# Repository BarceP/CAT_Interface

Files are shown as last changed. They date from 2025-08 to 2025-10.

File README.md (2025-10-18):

# CAT_Interface
Radio control and audio bridge.

- Isolated digital/audio Bridge
- Usb C (2.0) connector
- Analog Gain Control
- single DB9 output connector for easy cabling.

Version 2.0:

- Due to issues it was migrated to a uC for better compatibility (in revision an STM32F072)
- Still in development

Open Hardware (CERN OHW Licence)

## TODO

- [X] Connettore Prog.
- [X] Bypass Trafo
- [X] Opt aggiungere extra opto
- [X] Silkscreen (add Group)
- [X] Zenerino + R serie su TX
- [X] Togliere RS232
- [X] Verificare BOOT0

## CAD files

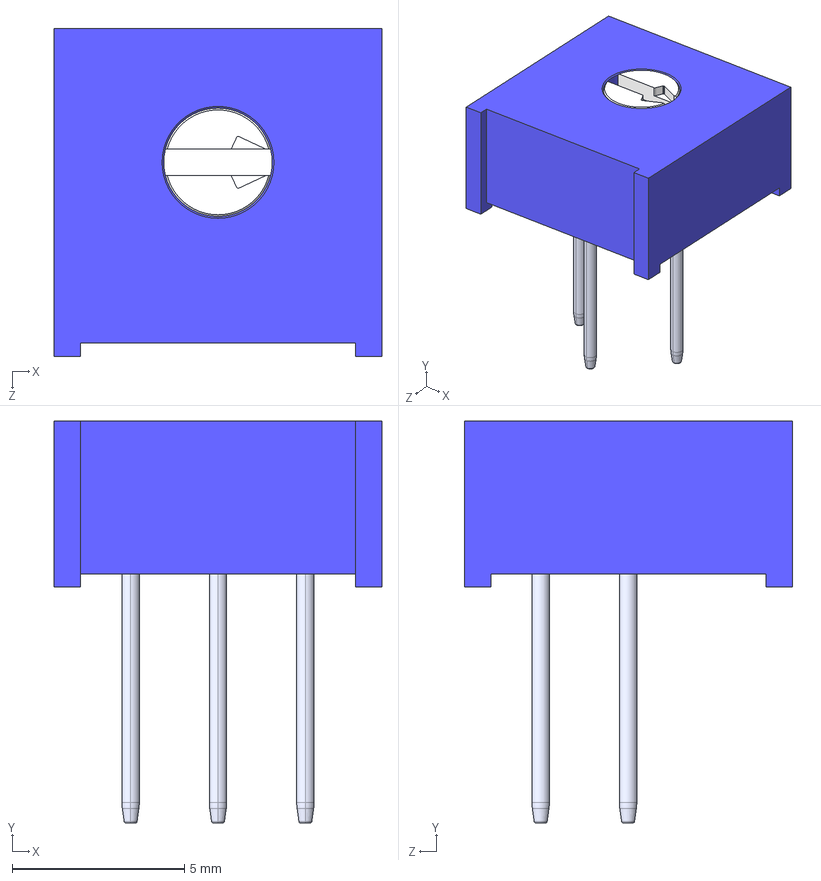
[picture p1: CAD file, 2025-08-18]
3386P-1-103.STEP
9.53 x 11.7 x 9.53 mm

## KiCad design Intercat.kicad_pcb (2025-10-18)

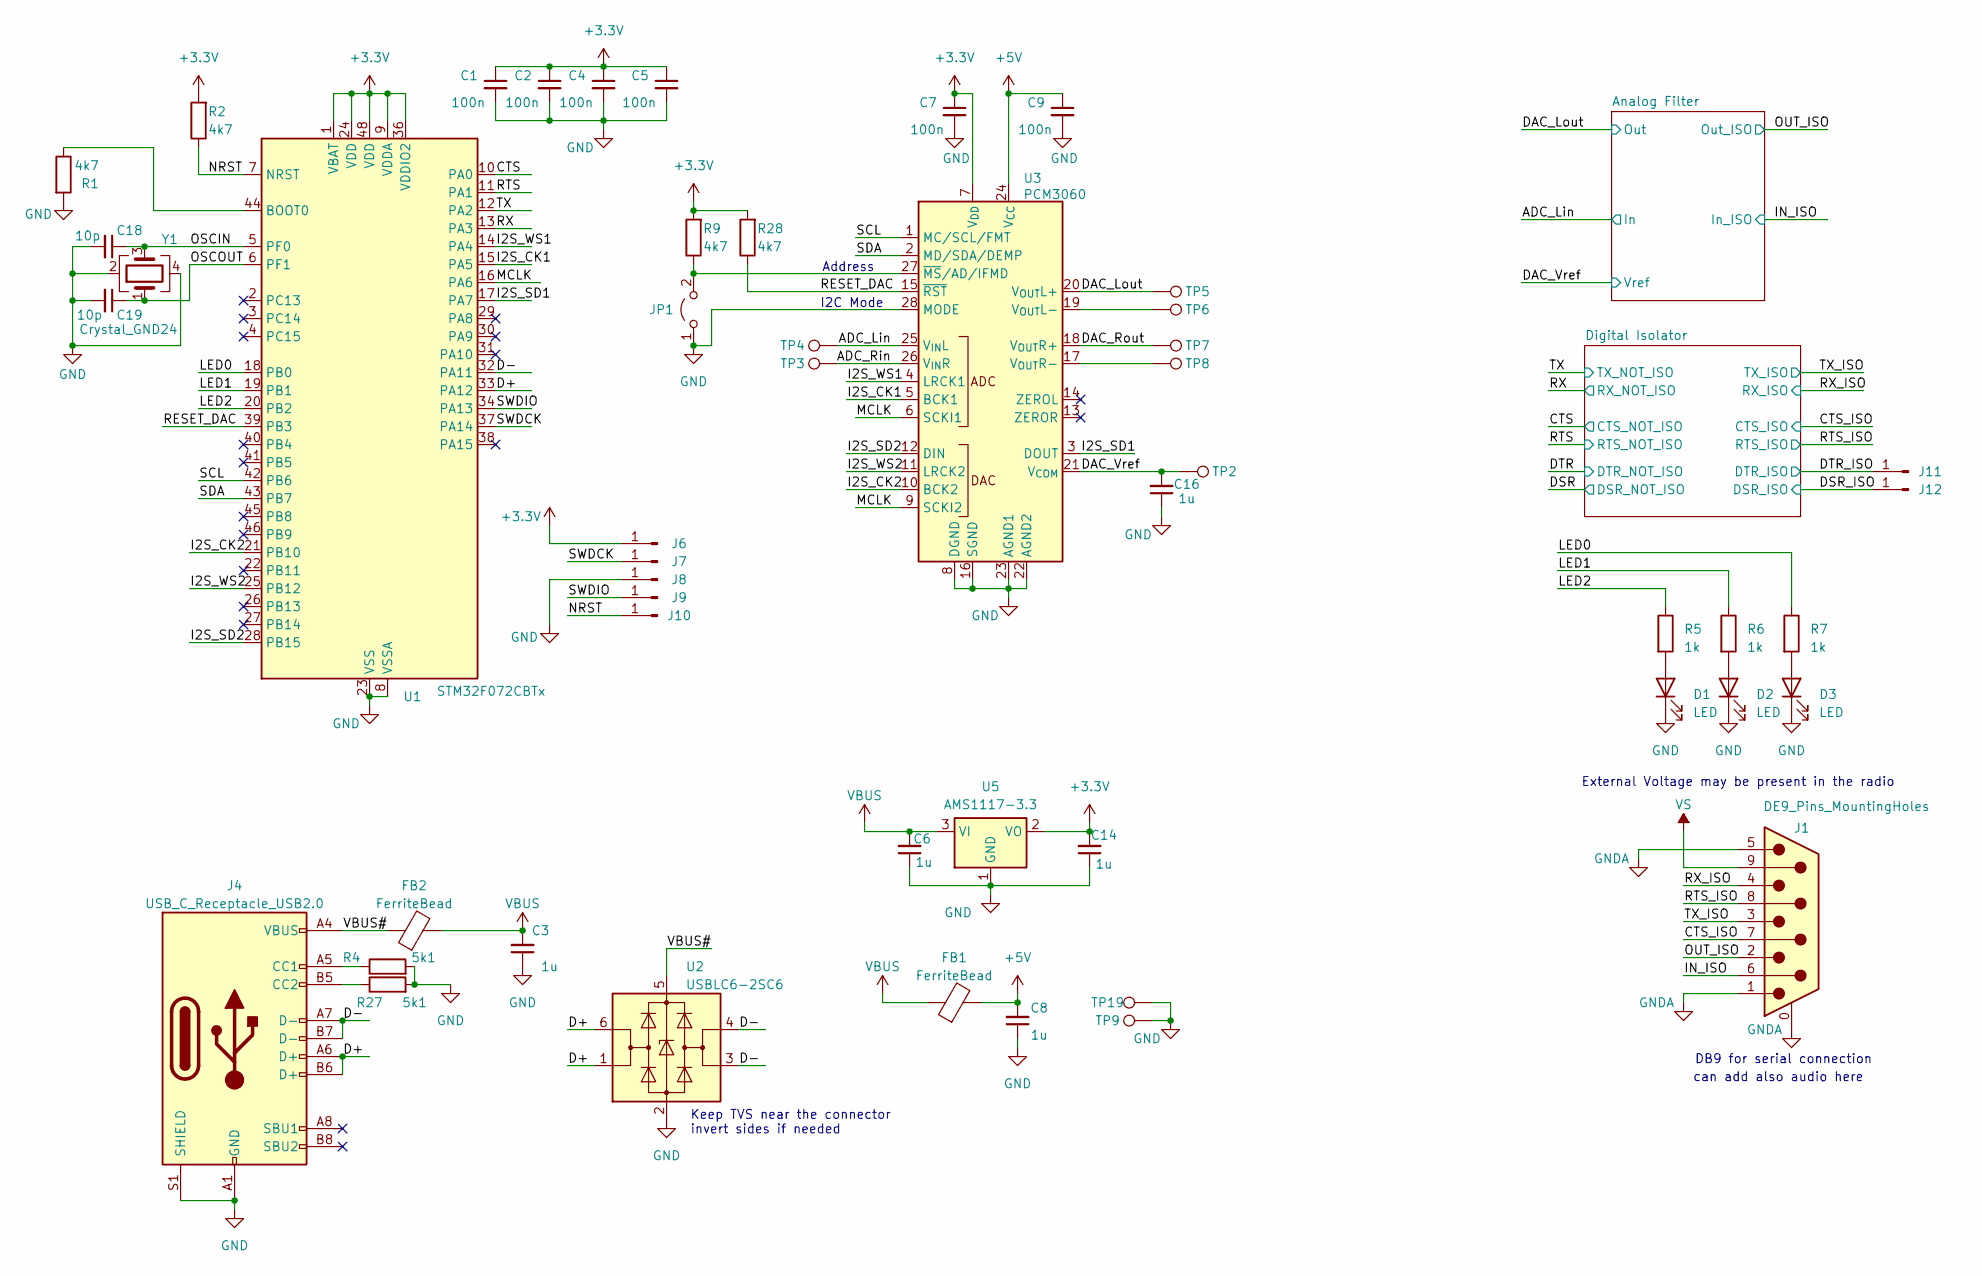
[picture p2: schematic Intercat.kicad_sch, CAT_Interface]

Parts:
C1, C2, C4, C5, C7, C9: 100n; C_0603_1608Metric; LCSC C14663
C3, C6, C8, C14, C16: 1u; C_0805_2012Metric; LCSC C28323
C18, C19: 10p; C_0603_1608Metric
D1, D2, D3: LED; LED_0603_1608Metric; LCSC C2286
FB1, FB2: FerriteBead; R_0603_1608Metric; LCSC C1002
J1: DE9_Pins_MountingHoles; DSUB-9_Pins_Horizontal_P2.77x2.84mm_EdgePinOffset4.94mm_Hou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
J4: USB_C_Receptacle_USB2.0; USB_C_Receptacle_GCT_USB4105-xx-A_16P_TopMnt_Horizontal; LCSC C2927038
J6, J11: Conn_01x01_Pin; SolderWirePad_1x01_SMD_1x2mm
J7, J12: SWDCLK; SolderWirePad_1x01_SMD_1x2mm
J8: GND; SolderWirePad_1x01_SMD_1x2mm
J9: SWDIO; SolderWirePad_1x01_SMD_1x2mm
J10: NRST; SolderWirePad_1x01_SMD_1x2mm
JP1: Jumper_2_Open; SolderJumper-2_P1.3mm_Open_RoundedPad1.0x1.5mm
R1, R2, R9, R28: 4k7; R_0603_1608Metric; LCSC C23162
R4, R27: 5k1; R_0603_1608Metric; LCSC C23186
R5, R6, R7: 1k; R_0603_1608Metric; LCSC C21190
TP2, TP3, TP4, TP5, TP6, TP7, TP8, TP9, TP19: TestPoint; TestPoint_Pad_D1.5mm
U1: STM32F072CBTx; LQFP-48_7x7mm_P0.5mm
U2: USBLC6-2SC6; SOT-23-6; LCSC C5261088
U3: PCM3060; TSSOP-28_4.4x9.7mm_P0.65mm
U5: AMS1117-3.3; SOT-223-3_TabPin2
Y1: Crystal_GND24; Crystal_SMD_3225-4Pin_3.2x2.5mm

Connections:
+3.3V: C1.1, C2.1, C4.1, C5.1, C7.1, C14.2, J6.1, R2.2, R9.2, R28.2, U1.1 (VBAT), U1.9 (VDDA), U1.24 (VDD), U1.36 (VDDIO2), U1.48 (VDD), U3.7 (V_{DD}), U5.2 (VO); also elsewhere on the board
+5V: C8.2, C9.1, FB1.2, U3.24 (V_{CC}); also elsewhere on the board
/ADC_Lin: TP4.1, U3.25 (V_{IN}L); also elsewhere on the board
/ADC_Rin: TP3.1, U3.26 (V_{IN}R)
/CTS: U1.10 (PA0); also elsewhere on the board
/CTS_ISO: J1.7; also elsewhere on the board
/D+: J4.A6 (D+), J4.B6 (D+), U1.33 (PA12), U2.1 (I/O1), U2.6 (I/O1)
/D-: J4.A7 (D-), J4.B7 (D-), U1.32 (PA11), U2.3 (I/O2), U2.4 (I/O2)
/DAC_Lout: TP5.1, U3.20 (V_{OUT}L+); also elsewhere on the board
/DAC_Rout: TP7.1, U3.18 (V_{OUT}R+)
/DAC_Vref: C16.2, TP2.1, U3.21 (V_{COM}); also elsewhere on the board
/DSR_ISO: J12.1; also elsewhere on the board
/DTR_ISO: J11.1; also elsewhere on the board
/I2S_CK1: U1.15 (PA5), U3.5 (BCK1)
/I2S_CK2: U1.21 (PB10), U3.10 (BCK2)
/I2S_SD1: U1.17 (PA7), U3.3 (DOUT)
/I2S_SD2: U1.28 (PB15), U3.12 (DIN)
/I2S_WS1: U1.14 (PA4), U3.4 (LRCK1)
/I2S_WS2: U1.25 (PB12), U3.11 (LRCK2)
/IN_ISO: J1.6; also elsewhere on the board
/LED0: R7.1, U1.18 (PB0)
/LED1: R6.1, U1.19 (PB1)
/LED2: R5.1, U1.20 (PB2)
/MCLK: U1.16 (PA6), U3.6 (SCKI1), U3.9 (SCKI2)
/NRST: J10.1, R2.1, U1.7 (NRST)
/OSCIN: C18.1, U1.5 (PF0), Y1.3
/OSCOUT: C19.1, U1.6 (PF1), Y1.1
/OUT_ISO: J1.2; also elsewhere on the board
/RESET_DAC: R28.1, U1.39 (PB3), U3.15 (~RST)
/RTS: U1.11 (PA1); also elsewhere on the board
/RTS_ISO: J1.8; also elsewhere on the board
/RX: U1.13 (PA3); also elsewhere on the board
/RX_ISO: J1.4; also elsewhere on the board
/SCL: U1.42 (PB6), U3.1 (MC/SCL/FMT)
/SDA: U1.43 (PB7), U3.2 (MD/SDA/DEMP)
/SWDCK: J7.1, U1.37 (PA14)
/SWDIO: J9.1, U1.34 (PA13)
/TX: U1.12 (PA2); also elsewhere on the board
/TX_ISO: J1.3; also elsewhere on the board
/VBUS#: FB2.1, J4.A4 (VBUS), J4.A9 (VBUS), J4.B4 (VBUS), J4.B9 (VBUS), U2.5 (VBUS)
GND: C1.2, C2.2, C3.1, C4.2, C5.2, C6.1, C7.2, C8.1, C9.2, C14.1, C16.1, C18.2, C19.2, D1.1 (K), D2.1 (K), D3.1 (K), J4.A1 (GND), J4.A12 (GND), J4.B1 (GND), J4.B12 (GND), J4.S1 (SHIELD), J8.1, JP1.1 (A), R1.2, R4.2, R27.2, TP9.1, TP19.1, U1.8 (VSSA), U1.23 (VSS), U1.35 (VSS), U1.47 (VSS), U2.2 (GND), U3.8 (DGND), U3.16 (SGND), U3.22 (AGND2), U3.23 (AGND1), U3.28 (MODE), U5.1 (GND), Y1.2, Y1.4; also elsewhere on the board
GNDA: J1.0 (PAD), J1.1, J1.5; also elsewhere on the board
unnamed: D1.2 (A), R5.2
unnamed: D2.2 (A), R6.2
unnamed: D3.2 (A), R7.2
unnamed: J4.A5 (CC1), R4.1
unnamed: J4.B5 (CC2), R27.1
unnamed: JP1.2 (B), R9.1, U3.27 (~MS/AD/IFMD)
unnamed: R1.1, U1.44 (BOOT0)
unnamed: TP6.1, U3.19 (V_{OUT}L-)
unnamed: TP8.1, U3.17 (V_{OUT}R-)
VBUS: C3.2, C6.2, FB1.1, FB2.2, U5.3 (VI)
VS: J1.9; also elsewhere on the board

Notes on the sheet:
can add also audio here
Address
External Voltage may be present in the radio
I2C Mode
DB9 for serial connection
Keep TVS near the connector invert sides if needed

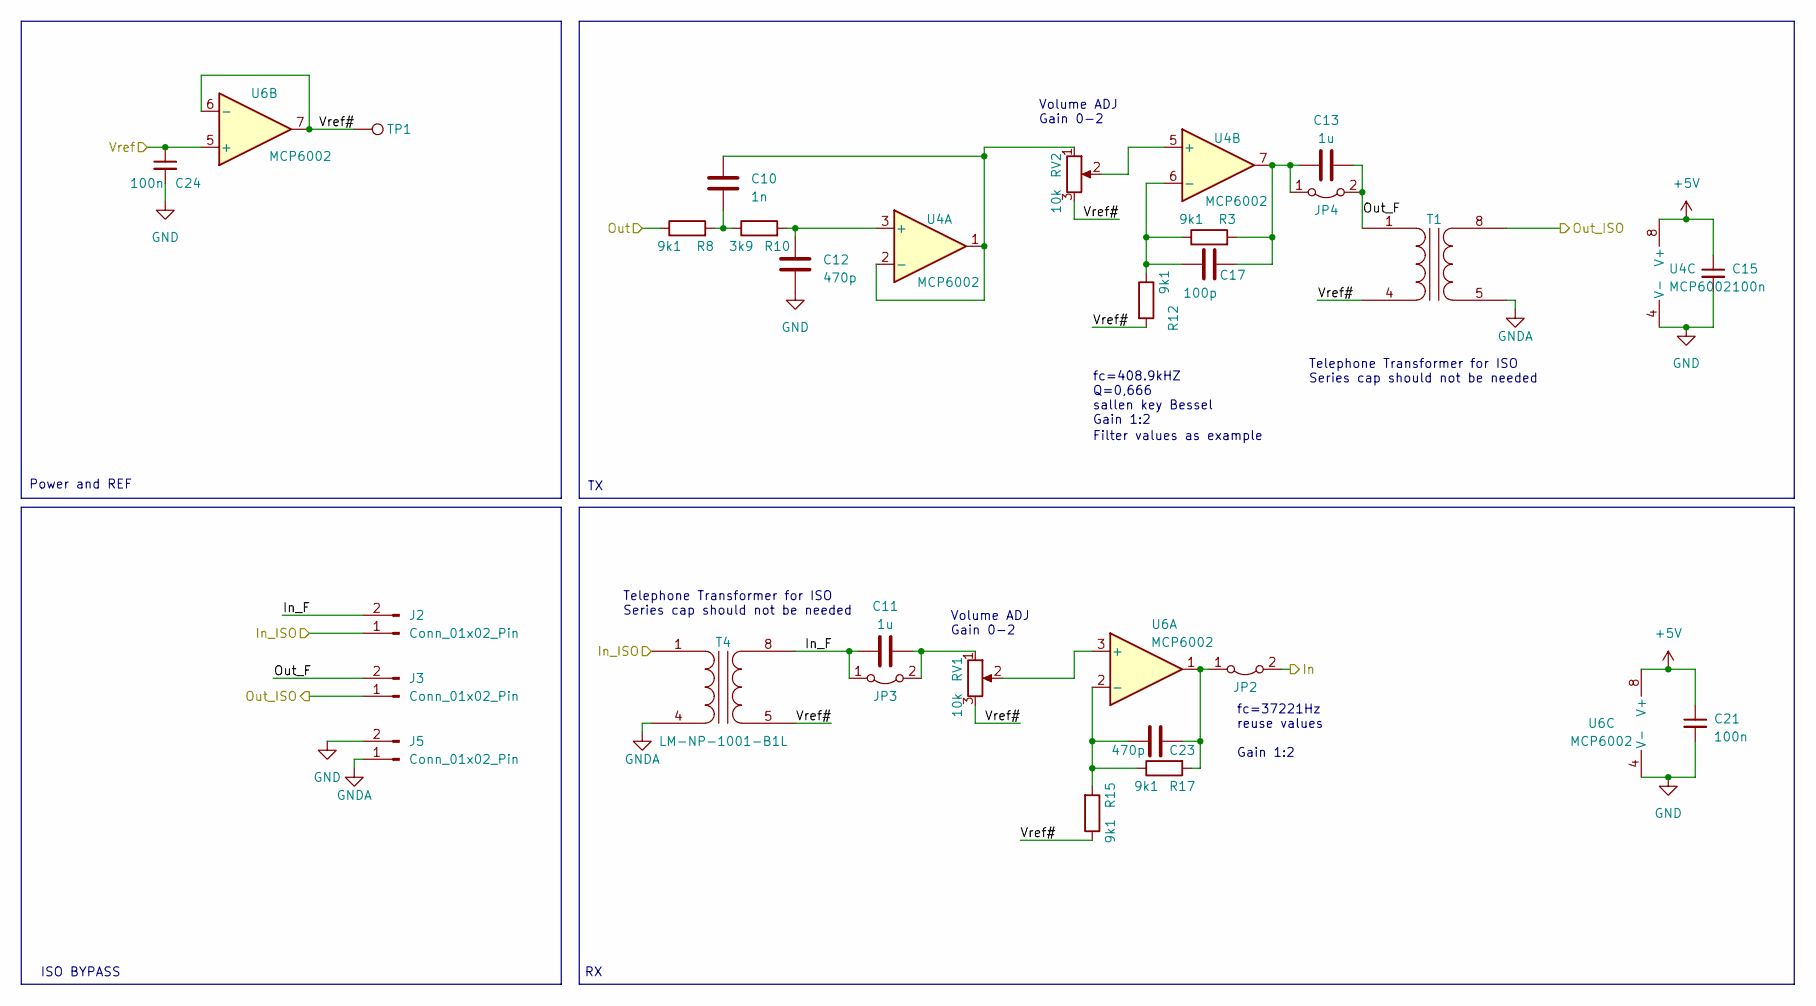
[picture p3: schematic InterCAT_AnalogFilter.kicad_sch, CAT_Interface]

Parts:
C10: 1n; C_0603_1608Metric
C11, C13: 1u; C_0805_2012Metric; LCSC C28323
C12, C23: 470p; C_0603_1608Metric; LCSC C1620
C15, C21, C24: 100n; C_0603_1608Metric; LCSC C14663
C17: 100p; C_0603_1608Metric
J2, J3, J5: Conn_01x02_Pin; PinHeader_1x02_P2.54mm_Vertical
JP2, JP3, JP4: Jumper_2_Bridged; SolderJumper-2_P1.3mm_Bridged_RoundedPad1.0x1.5mm
R3, R8, R12, R15, R17: 9k1; R_0603_1608Metric; LCSC C23260
R10: 3k9; R_0603_1608Metric; LCSC C23018
RV1, RV2: 10k; Potentiometer_Bourns_3386P_Vertical
T1, T4: LM-NP-1001-B1L; LCSC C5361839
TP1: TestPoint; TestPoint_Pad_D1.5mm
U4, U6: MCP6002; SOIC-8_3.9x4.9mm_P1.27mm; LCSC C7377

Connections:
+5V: C15.1, C21.1, U4.8 (V+), U6.8 (V+); also elsewhere on the board
/ADC_Lin: JP2.2 (B); also elsewhere on the board
/Analog Filter/In_F: C11.1, J2.2, JP3.1 (A), T4.8 (SB)
/Analog Filter/Out_F: C13.2, J3.2, JP4.2 (B), T1.1 (AA)
/Analog Filter/Vref#: R12.2, R15.1, RV1.3, RV2.3, T1.4 (AB), T4.5 (SA), TP1.1, U6.6 (-), U6.7
/DAC_Lout: R8.1; also elsewhere on the board
/DAC_Vref: C24.1, U6.5 (+); also elsewhere on the board
/IN_ISO: J2.1, T4.1 (AA); also elsewhere on the board
/OUT_ISO: J3.1, T1.8 (SB); also elsewhere on the board
GND: C12.2, C15.2, C21.2, C24.2, J5.2, U4.4 (V-), U6.4 (V-); also elsewhere on the board
GNDA: J5.1, T1.5 (SA), T4.4 (AB); also elsewhere on the board
unnamed: C10.2, R8.2, R10.1
unnamed: C23.2, JP2.1 (A), R17.2, U6.1
unnamed: C11.2, JP3.2 (B), RV1.1
unnamed: C13.1, C17.2, JP4.1 (A), R3.2, U4.7
unnamed: C12.1, R10.2, U4.3 (+)
unnamed: C10.1, RV2.1, U4.1, U4.2 (-)
unnamed: RV2.2, U4.5 (+)
unnamed: C17.1, R3.1, R12.1, U4.6 (-)
unnamed: RV1.2, U6.3 (+)
unnamed: C23.1, R15.2, R17.1, U6.2 (-)

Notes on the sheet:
Power and REF
fc=37221Hz reuse values Gain 1:2
Telephone Transformer for ISO Series cap should not be needed
Filter values as example
Volume ADJ Gain 0-2
fc=408.9kHZ Q=0,666 sallen key Bessel Gain 1:2
ISO BYPASS

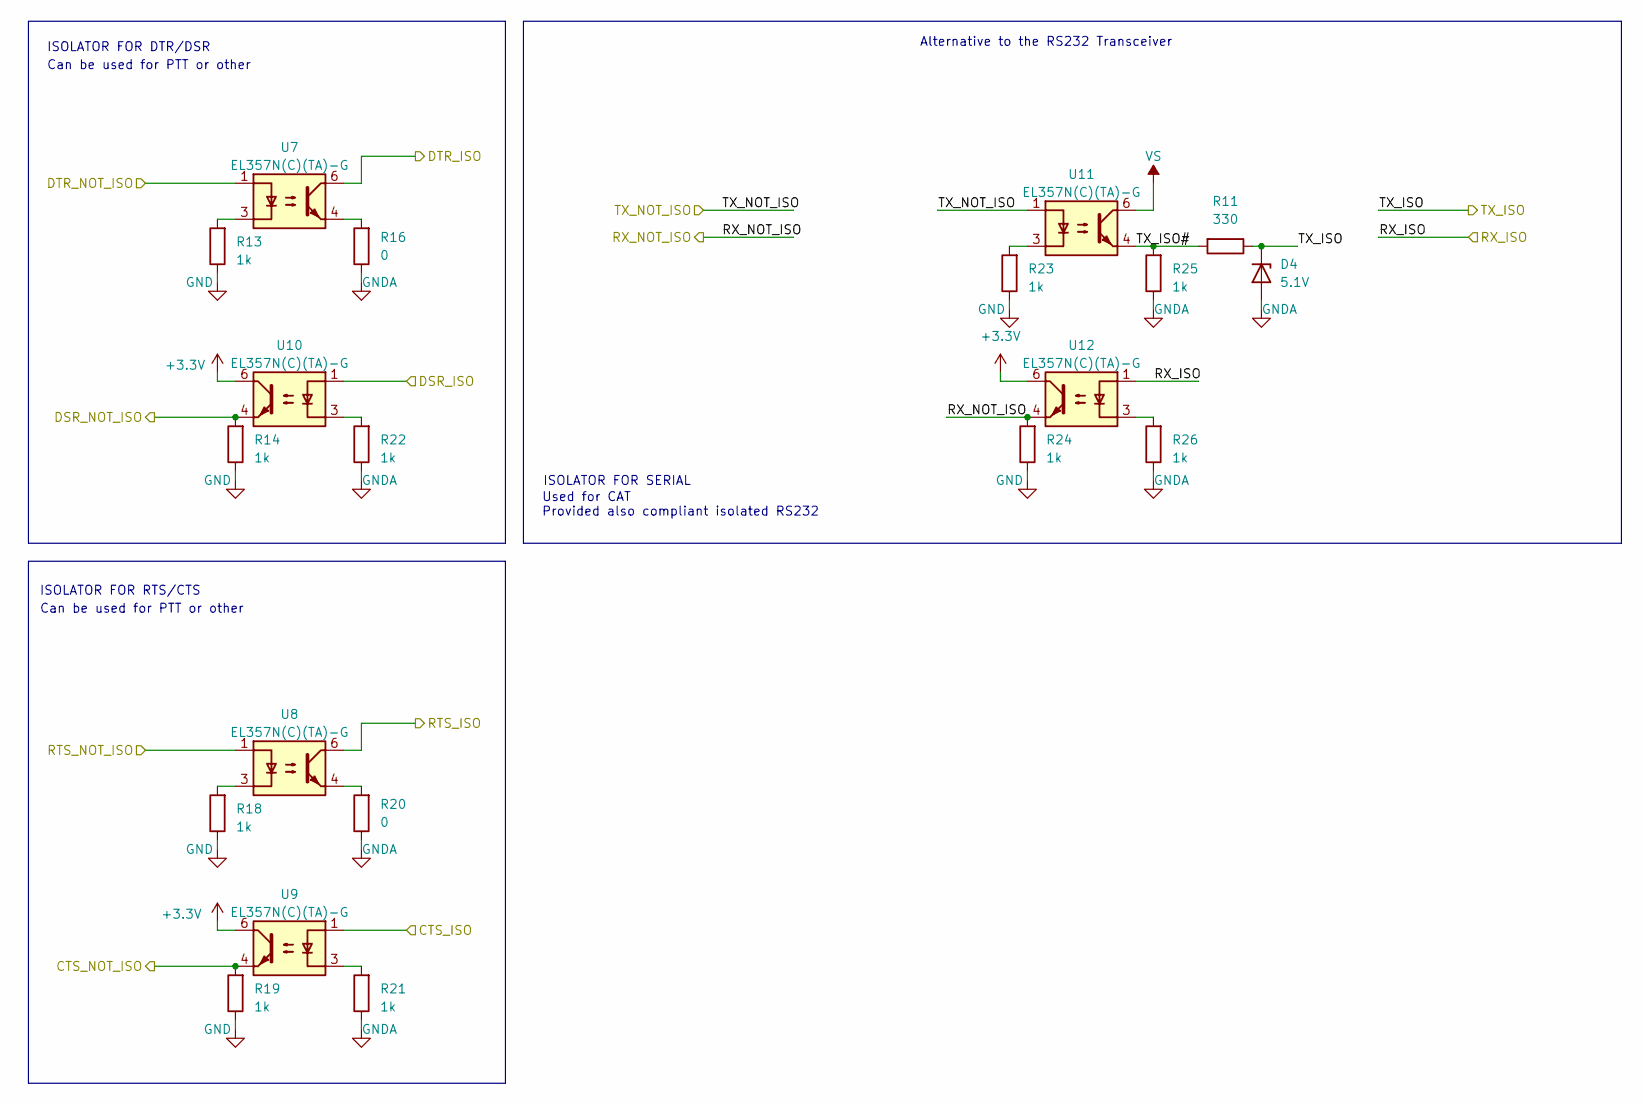
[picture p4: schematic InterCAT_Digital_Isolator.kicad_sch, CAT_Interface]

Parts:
D4: 5.1V; D_0603_1608Metric
R11: 330; R_0603_1608Metric
R13, R14, R18, R19, R21, R22, R23, R24, R25, R26: 1k; R_0603_1608Metric; LCSC C21190
R16, R20: 0; R_0603_1608Metric
U7, U8, U9, U10, U11, U12: EL357N(C)(TA)-G; SO-6-4_4.4x3.9mm_P2.54mm; LCSC C29981

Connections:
+3.3V: U9.6, U10.6, U12.6; also elsewhere on the board
/CTS: R19.2, U9.4; also elsewhere on the board
/CTS_ISO: U9.1; also elsewhere on the board
/DSR: R14.2, U10.4
/DSR_ISO: U10.1; also elsewhere on the board
/DTR: U7.1
/DTR_ISO: U7.6; also elsewhere on the board
/Digital Isolator/TX_ISO#: R11.2, R25.2, U11.4
/RTS: U8.1; also elsewhere on the board
/RTS_ISO: U8.6; also elsewhere on the board
/RX: R24.2, U12.4; also elsewhere on the board
/RX_ISO: U12.1; also elsewhere on the board
/TX: U11.1; also elsewhere on the board
/TX_ISO: D4.1 (K), R11.1; also elsewhere on the board
GND: R13.1, R14.1, R18.1, R19.1, R23.1, R24.1; also elsewhere on the board
GNDA: D4.2 (A), R16.1, R20.1, R21.1, R22.1, R25.1, R26.1; also elsewhere on the board
unnamed: R13.2, U7.3
unnamed: R16.2, U7.4
unnamed: R18.2, U8.3
unnamed: R20.2, U8.4
unnamed: R21.2, U9.3
unnamed: R22.2, U10.3
unnamed: R23.2, U11.3
unnamed: R26.2, U12.3
VS: U11.6; also elsewhere on the board

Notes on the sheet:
Can be used for PTT or other
ISOLATOR FOR DTR/DSR
ISOLATOR FOR RTS/CTS
Used for CAT Provided also compliant isolated RS232
Alternative to the RS232 Transceiver
ISOLATOR FOR SERIAL

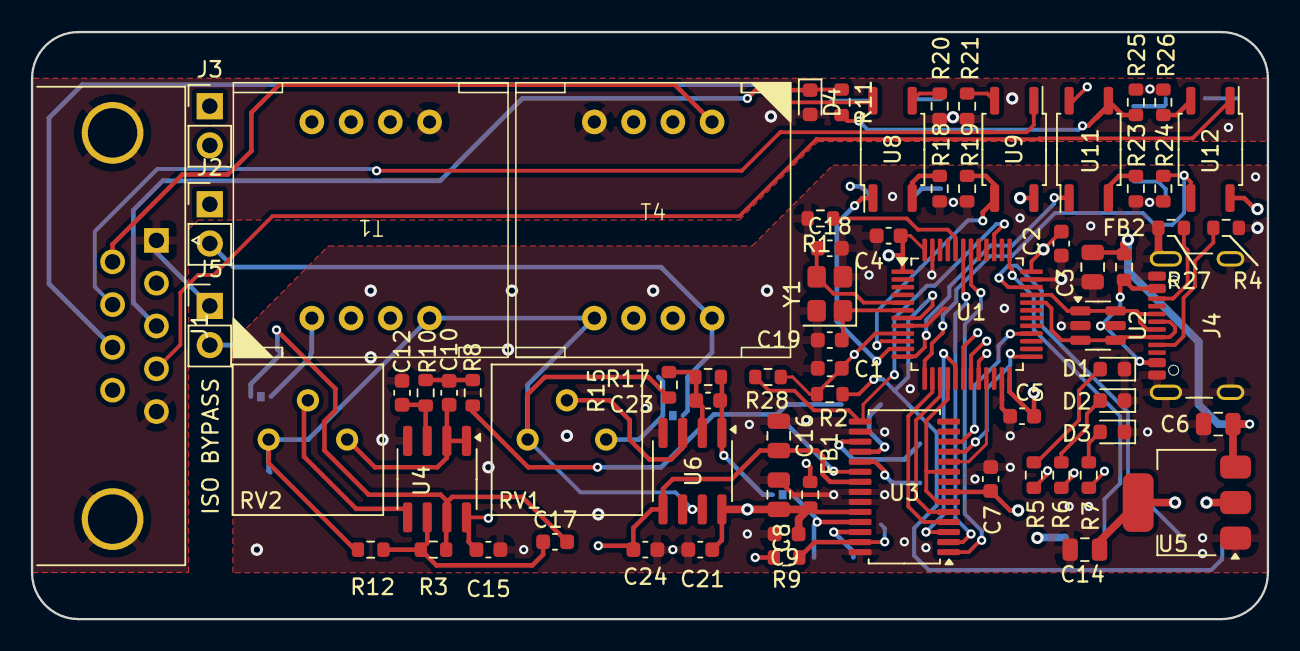
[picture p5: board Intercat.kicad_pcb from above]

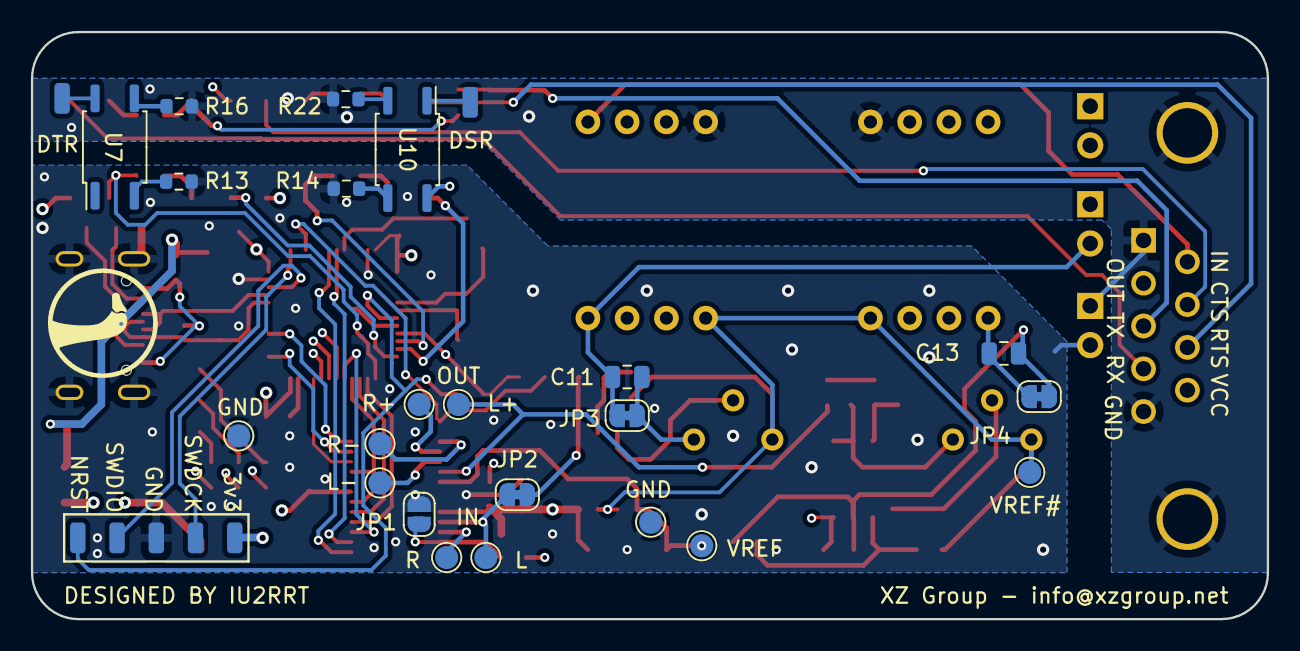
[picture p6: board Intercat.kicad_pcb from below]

Board: 4 copper layers, 80.0 x 38.0 mm, 99 parts (29 on the bottom side), 76 nets.

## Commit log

2023-05-27 First draft with new USB Bridge Added PCM3060 in library
    [Intercat.kicad_sch]
2023-05-28 added PCM3060 to schematic
    [Intercat.kicad_sch]
2023-05-28 added first draft of analog filters
    [Intercat.kicad_sch]
2023-05-28 tracked new schematic sheet
    [InterCAT_AnalogFilter.kicad_sch]
2023-05-28 added DB9 connector
    [InterCAT_AnalogFilter.kicad_sch, Intercat.kicad_sch]
2023-05-29 added trasf. on audio I/O added MAX3250 to library
    [InterCAT_AnalogFilter.kicad_sch, Intercat.kicad_sch]
2023-05-31 first dimensioning of filters, library of MAX33251
    [InterCAT_AnalogFilter.kicad_sch, Intercat.kicad_sch]
2023-06-17 First Draft of digital isolation part Modified MAX3250 Symbol Added sheet for digital isolation
    [InterCAT_Digital_Isolator.kicad_sch, Intercat.kicad_sch]
2023-06-17 changed analog filters, added gain
    [InterCAT_AnalogFilter.kicad_sch]
2023-06-18 added LEDs, small changes
    [InterCAT_AnalogFilter.kicad_sch, Intercat.kicad_sch]
2023-07-07 Started working on the PCB. alignement in analog channels. changed opamps ot Microchip RRIO basic on LCSC updated footprint on maxim Added LCSC parameter corrected some errors in GND/AGND corrected s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
    [InterCAT_AnalogFilter.kicad_sch, InterCAT_Digital_Isolator.kicad_sch, Intercat.kicad_pcb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]
2023-07-15 Corrected audio Jacks
    [InterCAT_AnalogFilter.kicad_sch, Intercat.kicad_pcb, Intercat.kicad_sch]
2023-07-15 Corrected hidden errors in power nets naming
    [InterCAT_AnalogFilter.kicad_sch, InterCAT_Digital_Isolator.kicad_sch, Intercat.kicad_sch]
2023-07-15 added footprints for trimmers and trasf
    [InterCAT_AnalogFilter.kicad_sch]
2023-07-15 corrected footprint AND symbol of trasf
    [InterCAT_AnalogFilter.kicad_sch, Intercat.kicad_pcb]
2023-07-15 first PCB placement Draft
    [Intercat.kicad_pcb]
2023-07-15 removed jack connectors, added testpoints on DAC
    [InterCAT_AnalogFilter.kicad_sch, InterCAT_Digital_Isolator.kicad_sch, Intercat.kicad_pcb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]
2023-07-17 updated hole size on transformer pcb
    [Intercat.kicad_pcb]
2023-07-22 changed optocouplers, started compiling BOM
    [InterCAT_AnalogFilter.kicad_sch, InterCAT_Digital_Isolator.kicad_sch, Intercat.kicad_sch]
2023-07-22 continuation on BOM
    [InterCAT_AnalogFilter.kicad_sch, InterCAT_Digital_Isolator.kicad_sch, Intercat.kicad_sch]
2023-07-22 added FB2 and continued with BOM
    [InterCAT_AnalogFilter.kicad_sch, Intercat.kicad_sch]
2023-07-22 completed JLC BOM and changed DB9
    [InterCAT_Digital_Isolator.kicad_sch, Intercat.kicad_sch]
2023-07-22 added edge cuts, smaller PCB, bugfix
    [InterCAT_Digital_Isolator.kicad_sch, Intercat.kicad_pcb]
2023-07-24 changed 3d model of the transformer
    [Intercat.kicad_pcb, Intercat.kicad_sch]
2023-07-24 changed schematic to full mono
    [InterCAT_AnalogFilter.kicad_sch, Intercat.kicad_sch]
2023-07-24 reduced PCB size, started routing
    [InterCAT_Digital_Isolator.kicad_sch, Intercat.kicad_pcb, Intercat.kicad_sch]
2023-07-25 redone layout, reduced size, added clearance for box
    [Intercat.kicad_pcb, Intercat.kicad_sch]
2023-07-25 redone analog channels to improve dynamic range, removed DC block
    [InterCAT_AnalogFilter.kicad_sch, Intercat.kicad_sch]
2023-07-25 removed missed cap,reviewed layout
    [InterCAT_AnalogFilter.kicad_sch, InterCAT_Digital_Isolator.kicad_sch, Intercat.kicad_pcb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]
2023-07-28 corrected gain of the amplifiers and dyn range, continued PCB
    [InterCAT_AnalogFilter.kicad_sch, InterCAT_Digital_Isolator.kicad_sch, Intercat.kicad_pcb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]
2023-08-02 first PCB version
    [Intercat.kicad_pcb]
2023-08-02 reviewed silkscreen
    [Intercat.kicad_pcb]
2023-08-06 little pcb modification and silkscreen
    [Intercat.kicad_pcb]
2023-08-06 little pcb modification
    [Intercat.kicad_pcb]
2023-08-13 modified silkscreen
    [Intercat.kicad_pcb]
2025-08-17 Started Version 2.0, migrated to STM32, changed some symbols, added 3V3 Supply
    [InterCAT_AnalogFilter.kicad_sch, InterCAT_Digital_Isolator.kicad_sch, Intercat.kicad_sch]
2025-08-17 Started work on the PBClayout of the new version
    [InterCAT_Digital_Isolator.kicad_sch, Intercat.kicad_pcb, Intercat.kicad_sch]
2025-08-18 First PCB version complete, to review, added 3D, changed DB9 Connecto
    [Intercat.kicad_pcb, Intercat.kicad_sch]
2025-08-18 added 3d files
    [3386P-1-103.STEP]
2025-08-18 added trafo bypass, added zener reg, added todo
    [InterCAT_AnalogFilter.kicad_sch, InterCAT_Digital_Isolator.kicad_sch, Intercat.kicad_pcb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]
2025-08-22 added iso bypass, removed RS232, added Extra opto and prog connector
    [InterCAT_AnalogFilter.kicad_sch, InterCAT_Digital_Isolator.kicad_sch, Intercat.kicad_pcb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]
2025-10-18 added DAC_RESET and routed
    [Intercat.kicad_pcb, Intercat.kicad_sch]
